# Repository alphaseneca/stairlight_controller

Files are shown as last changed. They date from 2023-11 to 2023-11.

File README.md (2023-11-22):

# stairlight_controller

This GitHub repository houses the code and documentation for a Two-Way Passive Infrared (PIR) Stairlight Controller. The controller incorporates PIR sensors to detect motion in both ascending and descending directions, ensuring that the stairlights illuminate when needed and conserve energy when not in use.

## Schematic

The schematic for the device connection is shown below.

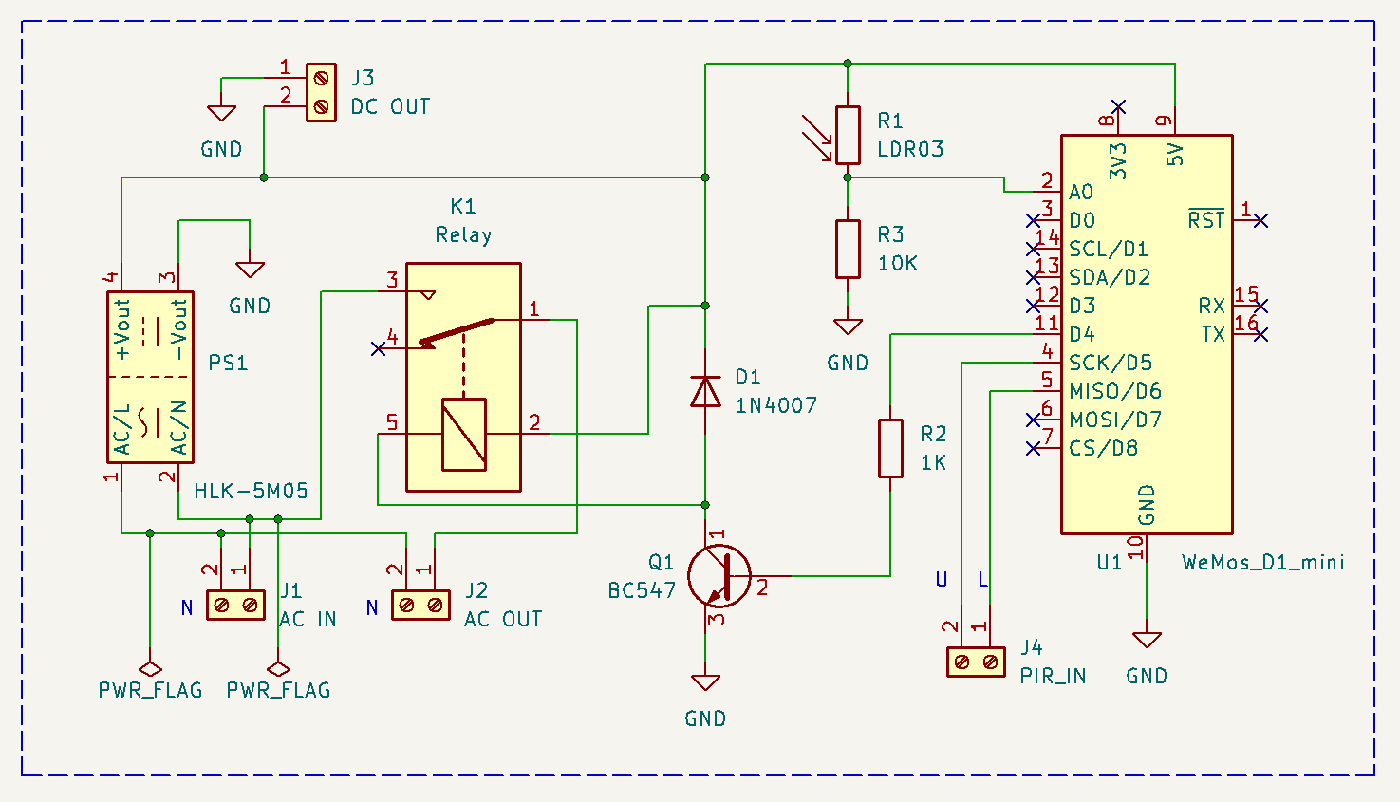
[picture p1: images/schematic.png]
schematic


## Setting it up.

**Translating Schematic to PCB and Integrating Components:**
Following the meticulous design of the schematic, the next phase involves transposing this plan onto a printed circuit board (PCB). For rapid prototyping and flexibility, a prefboard serves as an excellent choice to bring the schematic to life. This stage allows for a physical manifestation of the electronic layout, facilitating quick adjustments and component placements as needed. Upon transferring the design, selecting an appropriate housing for the circuit becomes pivotal. The chosen housing not only provides protection but also accommodates the PCB and its components snugly. Additionally, this phase involves the crucial step of integrating Passive Infrared (PIR) sensors into the controller setup. These sensors, once connected, enable the controller to detect motion effectively and trigger the desired response in the staircase lighting system. Assembling the components within the selected housing, ensuring meticulous connections between the PCB, PIR sensors, and the controller, ensures a cohesive and functional unit.

---

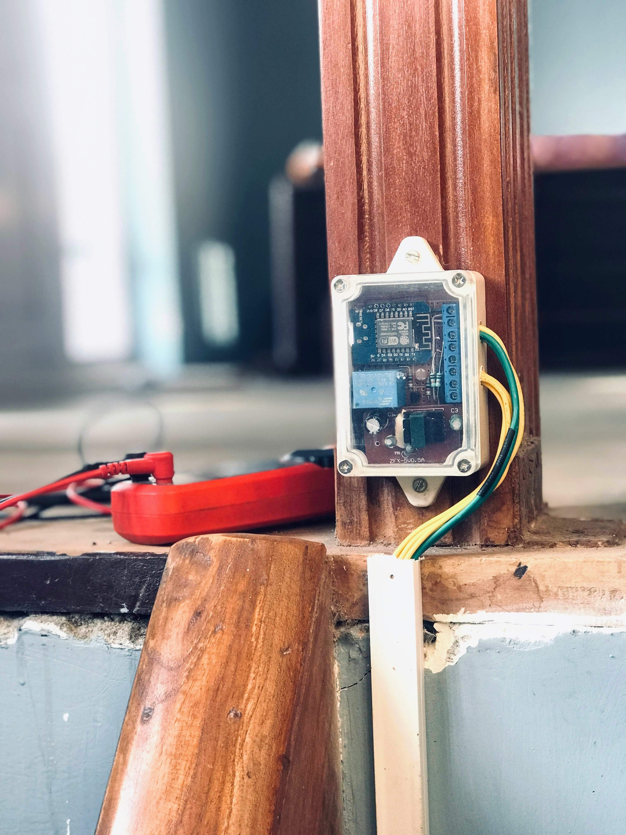
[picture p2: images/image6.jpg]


---

## PIR Sensors

The PIR sensors are connected to the controller's input pins. These sensors are mounted on the poles of the stairs beforehand and are used to detect motion in both ascending and descending directions.

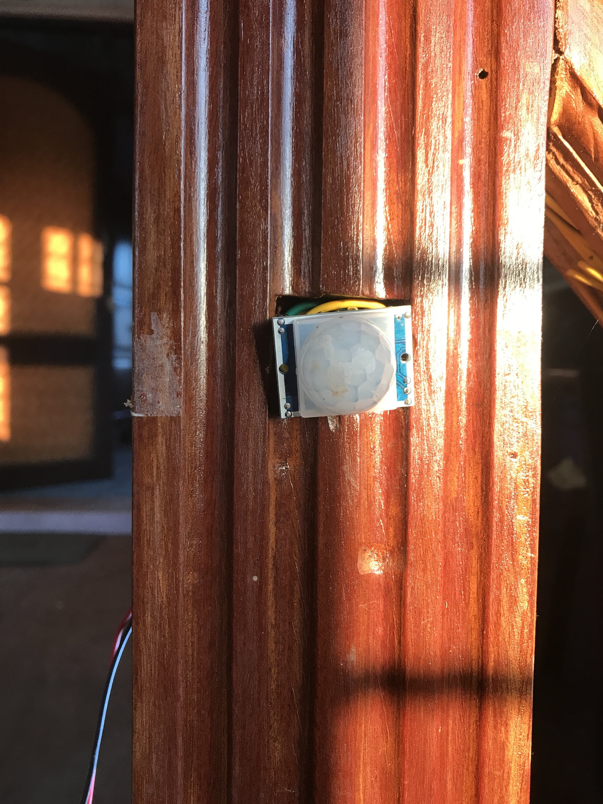
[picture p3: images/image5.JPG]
pirsensor


## Addressing False Triggers:

During the integration phase, an important realization surfaced regarding the initial setup. Due to the absence of pull-down resistors, certain values were floating, leading to sporadic false triggers within the system. To rectify this issue and ensure stable operation, 10k resistors were strategically added. These resistors served as pull-down components, stabilizing the values and preventing erratic triggering, thus enhancing the reliability and accuracy of the staircase light controller's functionality.

## More Images of the setup.

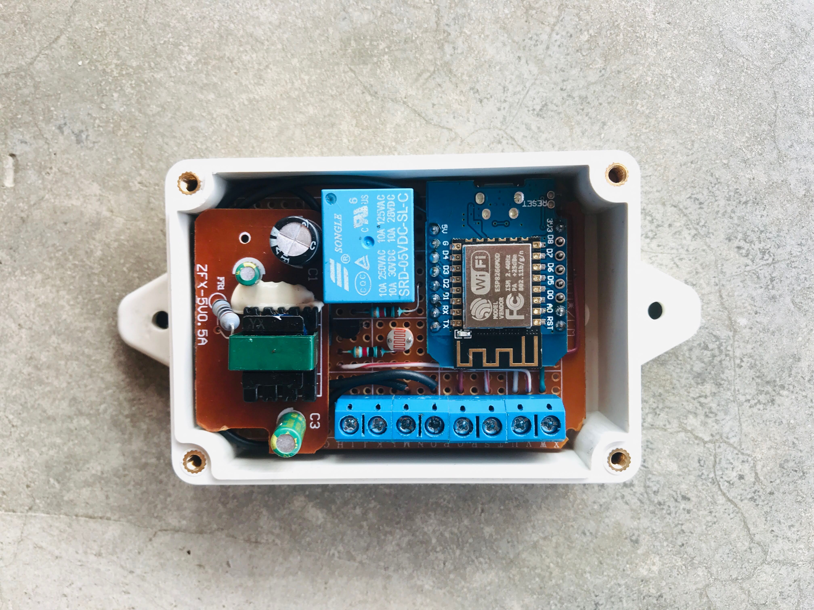
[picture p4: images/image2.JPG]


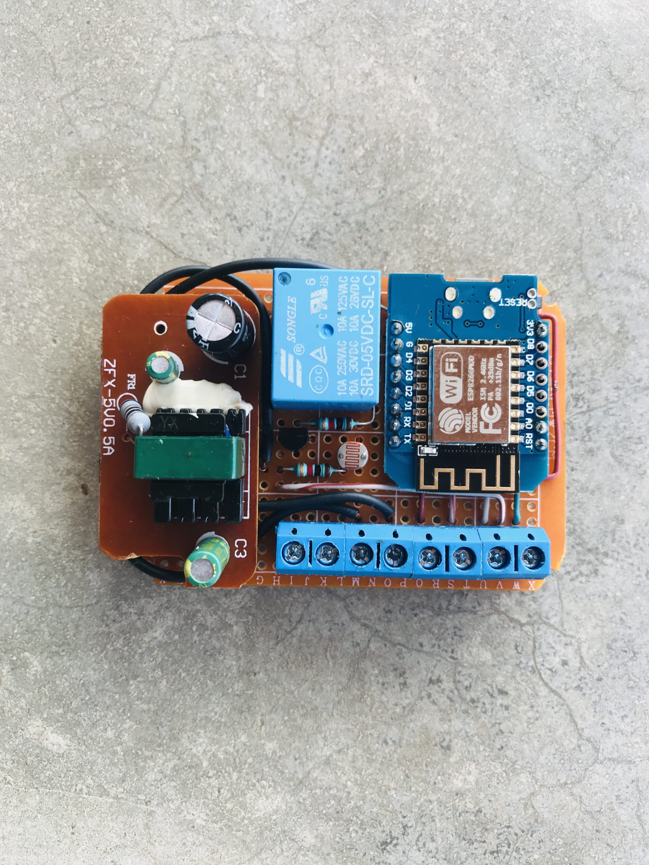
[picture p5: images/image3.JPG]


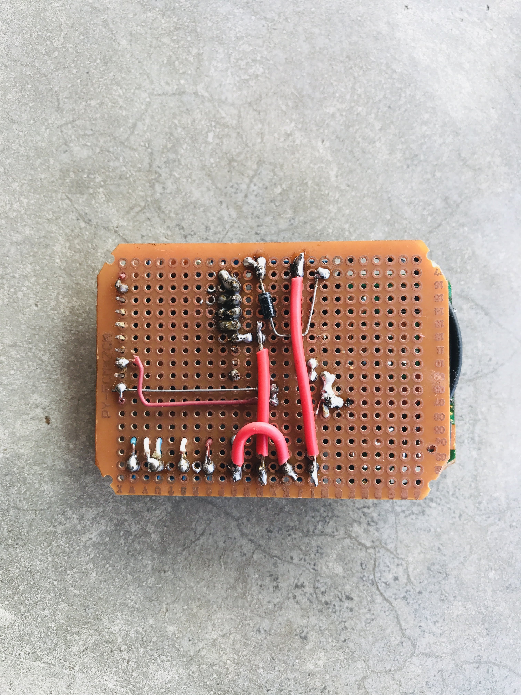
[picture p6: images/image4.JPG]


## Code

The code for the controller is available on GitHub.
[\stairlight_controller_code](https://github.com/alphaseneca/stairlight_controller/tree/master/stairlight_controller_code)

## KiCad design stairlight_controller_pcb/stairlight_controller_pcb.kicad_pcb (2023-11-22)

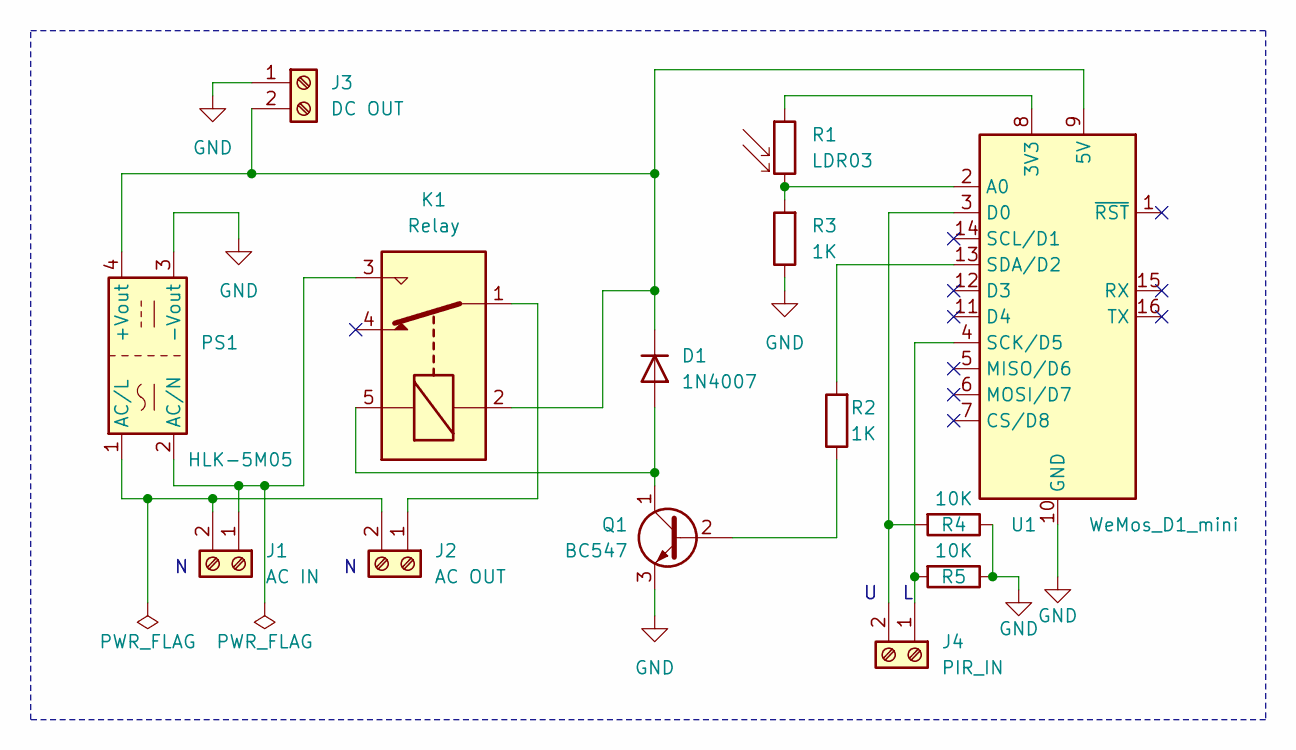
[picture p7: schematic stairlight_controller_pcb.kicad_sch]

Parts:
D1: 1N4007; D_DO-41_SOD81_P10.16mm_Horizontal
J1: AC IN; TerminalBlock_Altech_AK300-2_P5.00mm
J2: AC OUT; TerminalBlock_Altech_AK300-2_P5.00mm
J3: DC OUT; TerminalBlock_Altech_AK300-2_P5.00mm
J4: PIR_IN; TerminalBlock_Altech_AK300-2_P5.00mm
K1: Relay; Relay_SPDT_SANYOU_SRD_Series_Form_C
PS1: HLK-5M05; Converter_ACDC_HiLink_HLK-5Mxx
Q1: BC547; TO-92_Inline
R1: LDR03; R_LDR_5.0x4.1mm_P3mm_Vertical
R2, R3: 1K; R_Axial_DIN0204_L3.6mm_D1.6mm_P5.08mm_Horizontal
R4, R5: 10K; R_Axial_DIN0204_L3.6mm_D1.6mm_P5.08mm_Horizontal
U1: WeMos_D1_mini; WEMOS_D1_mini_light

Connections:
GND: J3.1, PS1.3 (-Vout), Q1.3 (E), R3.1, R4.1, R5.1, U1.10 (GND)
unnamed: D1.2 (A), K1.5, Q1.1 (C)
unnamed: D1.1 (K), J3.2, K1.2, PS1.4 (+Vout), U1.9 (5V)
unnamed: J1.1, K1.3, PS1.2 (AC/N)
unnamed: J1.2, J2.2, PS1.1 (AC/L)
unnamed: J2.1, K1.1
unnamed: J4.1, R5.2, U1.4 (SCK/D5)
unnamed: J4.2, R4.2, U1.3 (D0)
unnamed: Q1.2 (B), R2.1
unnamed: R1.1, U1.8 (3V3)
unnamed: R1.2, R3.2, U1.2 (A0)
unnamed: R2.2, U1.13 (SDA/D2)

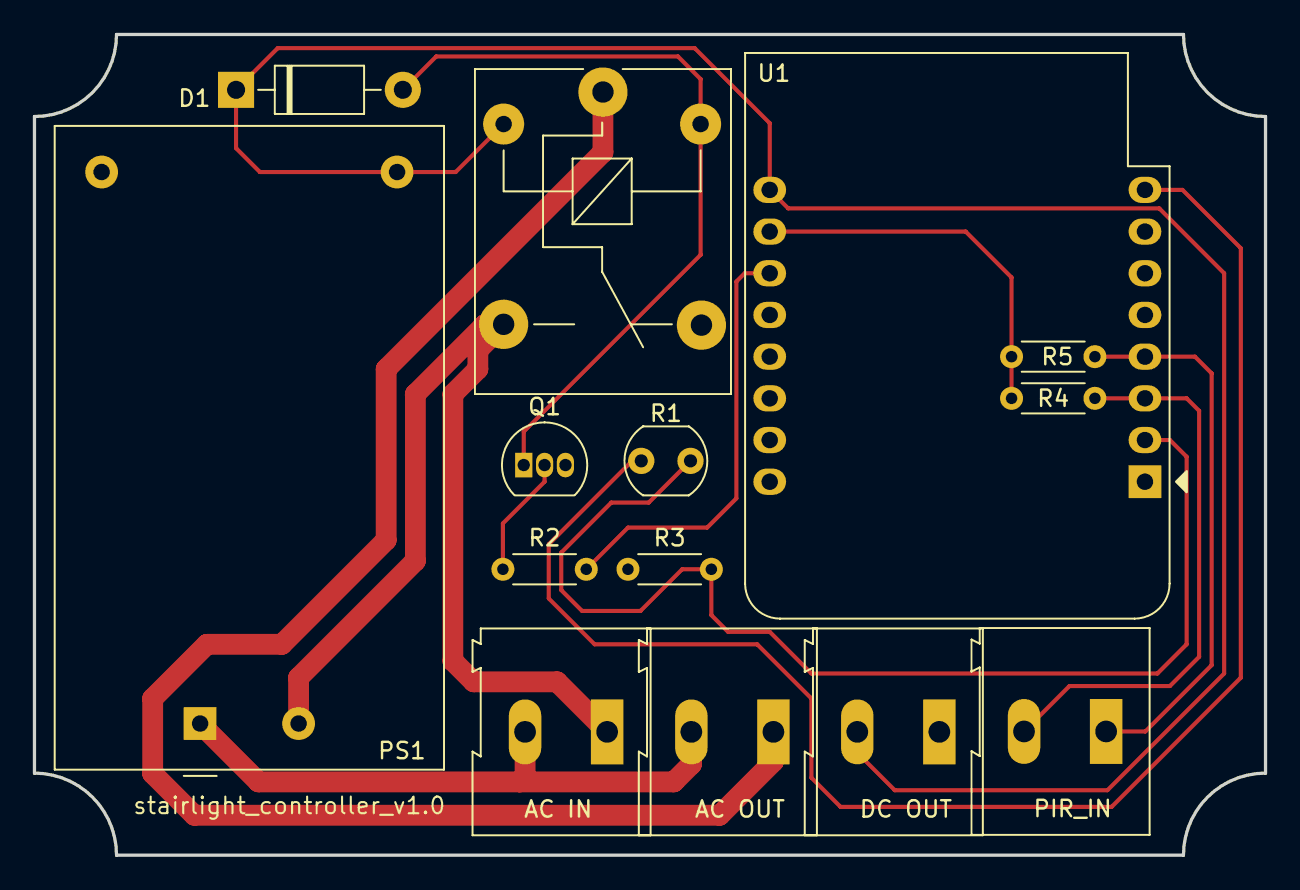
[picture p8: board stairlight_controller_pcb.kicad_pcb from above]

Board: 2 copper layers, 75.0 x 50.0 mm, 14 parts (0 on the bottom side), 12 nets.

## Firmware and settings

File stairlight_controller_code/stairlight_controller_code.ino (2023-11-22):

/* 
This is the code for the stairlight_controller.
Author: Ukesh Aryal
Date Created: 22/11/2023
*/

const int lower_pir_pin = D5;   // Set the lower_pir_pin
const int upper_pir_pin = D0;   // Set the upper_pir_pin
const int relay_pin = D2;       // Set the relay pin
const int led_pin = D4;         // Set the led pin
bool lower_pir = 0;             // Initialize all the flag and setup values as 0. 
bool upper_pir = 0;
bool lowerflag = 0;
bool upperflag = 0;
uint16_t threshold = 45;   // Light threshold that if crossed below activates the system.
uint16_t hold_time = 20;   // Time for the light to remain on.


void setup() {
  Serial.begin(9600);
  Serial.println("Hello, stairlight_controller!");

  pinMode(lower_pir_pin, INPUT);    // Define all the pin functions.
  pinMode(upper_pir_pin, INPUT);
  pinMode(relay_pin, OUTPUT);
  pinMode(led_pin, OUTPUT);
}


void readinput() {                  // Takes the input from the pins and sets the value of the flag.

  lower_pir = digitalRead(lower_pir_pin);
  upper_pir = digitalRead(upper_pir_pin);

  if (lower_pir == 1 && lowerflag == 0 && upperflag == 0) {
    lowerflag = 1;
  }
  if (upper_pir == 1 && lowerflag == 0 && upperflag == 0) {
    upperflag = 1;
  }
}

void stairlight() {                 /*  Checks the flag and if the flag is high then turns off
                                        the input for the time the light is on.  */
  if (lowerflag == 1) {

    Serial.println("Motion Detected. L_U");
    digitalWrite(relay_pin, HIGH);
    for (int i = 0; i <= hold_time; i++) {
      Serial.println(i);
      delay(1000);
    }
    Serial.println("Motion Timeout");
    lowerflag = 0;
    digitalWrite(relay_pin, LOW);
  }


  else if (upperflag == 1) {
    Serial.println("Motion Detected. U_L");
    digitalWrite(relay_pin, HIGH);
    for (int i = 0; i <= hold_time; i++) {
      Serial.println(i);
      delay(1000);
    }
    Serial.println("Motion Timeout");
    upperflag = 0;
    digitalWrite(relay_pin, LOW);
  }

  else {
    digitalWrite(relay_pin, LOW);
  }
}

void loop() {

  int ldr_value = analogRead(A0);       // Store the analogvalue read from A0 to the ldr_value.

  Serial.println(ldr_value);            
  if (ldr_value <= threshold){          // If the ldr_value is less than the threshold then it activates the system.
    Serial.println("Stairlights Active.");
    digitalWrite(led_pin, HIGH);        // Activate the on_board led
    readinput();
    stairlight();
  }

  else {
  digitalWrite(relay_pin, LOW);
  }
  delay(1);                              // Delay in between reads for stability



}

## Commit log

2023-11-06 Added pcb files
    [stairlight_controller_pcb.kicad_pcb, stairlight_controller_pcb.kicad_sch]
2023-11-06 Added schematic
2023-11-06 Added schematic on readme
2023-11-22 Final Schematic and PCB
    [stairlight_controller_pcb.kicad_pcb, stairlight_controller_pcb.kicad_sch]
